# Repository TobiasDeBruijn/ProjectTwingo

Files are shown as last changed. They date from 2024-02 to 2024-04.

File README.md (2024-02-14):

# Project Twingo
I own a Renault Twingo Initiale from 2002. This car originally shipped with a simple FM radio, that wasn't enough.

## Goals
With this project I'm trying to do the following:
- Add Android Auto to the Twingo, both wireless and via USB
    - Retain the steering wheel controls
- Interior lighting
    - Replace ceiling light with LED
    - Feet of front passengers
- Replace the standard display in the middle of the dashboard? (Mine is sortof broken)
- Control AC electronically with a thermostat?

## License
All work in this project is licensed under the MIT license.

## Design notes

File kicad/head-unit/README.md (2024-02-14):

# Head unit
The 'head unit' and all the required additional stuff

## head-unit
This is the main bit of the unit. This contains the STM32 microcontroller, the Raspberry Pi running Android Auto, the DAC and various controlling relays.

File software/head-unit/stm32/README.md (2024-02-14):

# stm32-cmake-template

## Requirments
- `gcc-arm-linux-gnueabihf`
- `openocd`
- `cmake`
- `make`

## Building 
From `$ROOT/software/head-unit/stm32/`:
1. `cmake -B build -DCMAKE_BUILD_TYPE=Debug`
>Building in `Release` mode somehow causes issues
2. `cd build/`
3. `make`

## Uploading
From the repository root:
1. `openocd -f openocd-stlink.cfg -c "program build/head-unit.elf verify reset exit"`

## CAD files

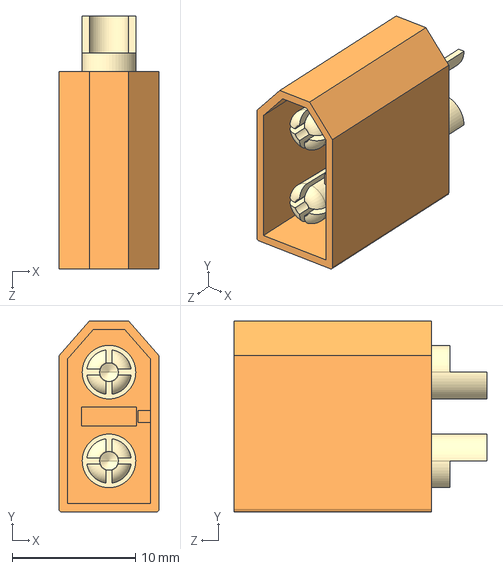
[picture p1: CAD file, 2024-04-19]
kicad/head-unit/external_symbols/xt60/XT60-M.step
8.10 x 15.5 x 20.5 mm

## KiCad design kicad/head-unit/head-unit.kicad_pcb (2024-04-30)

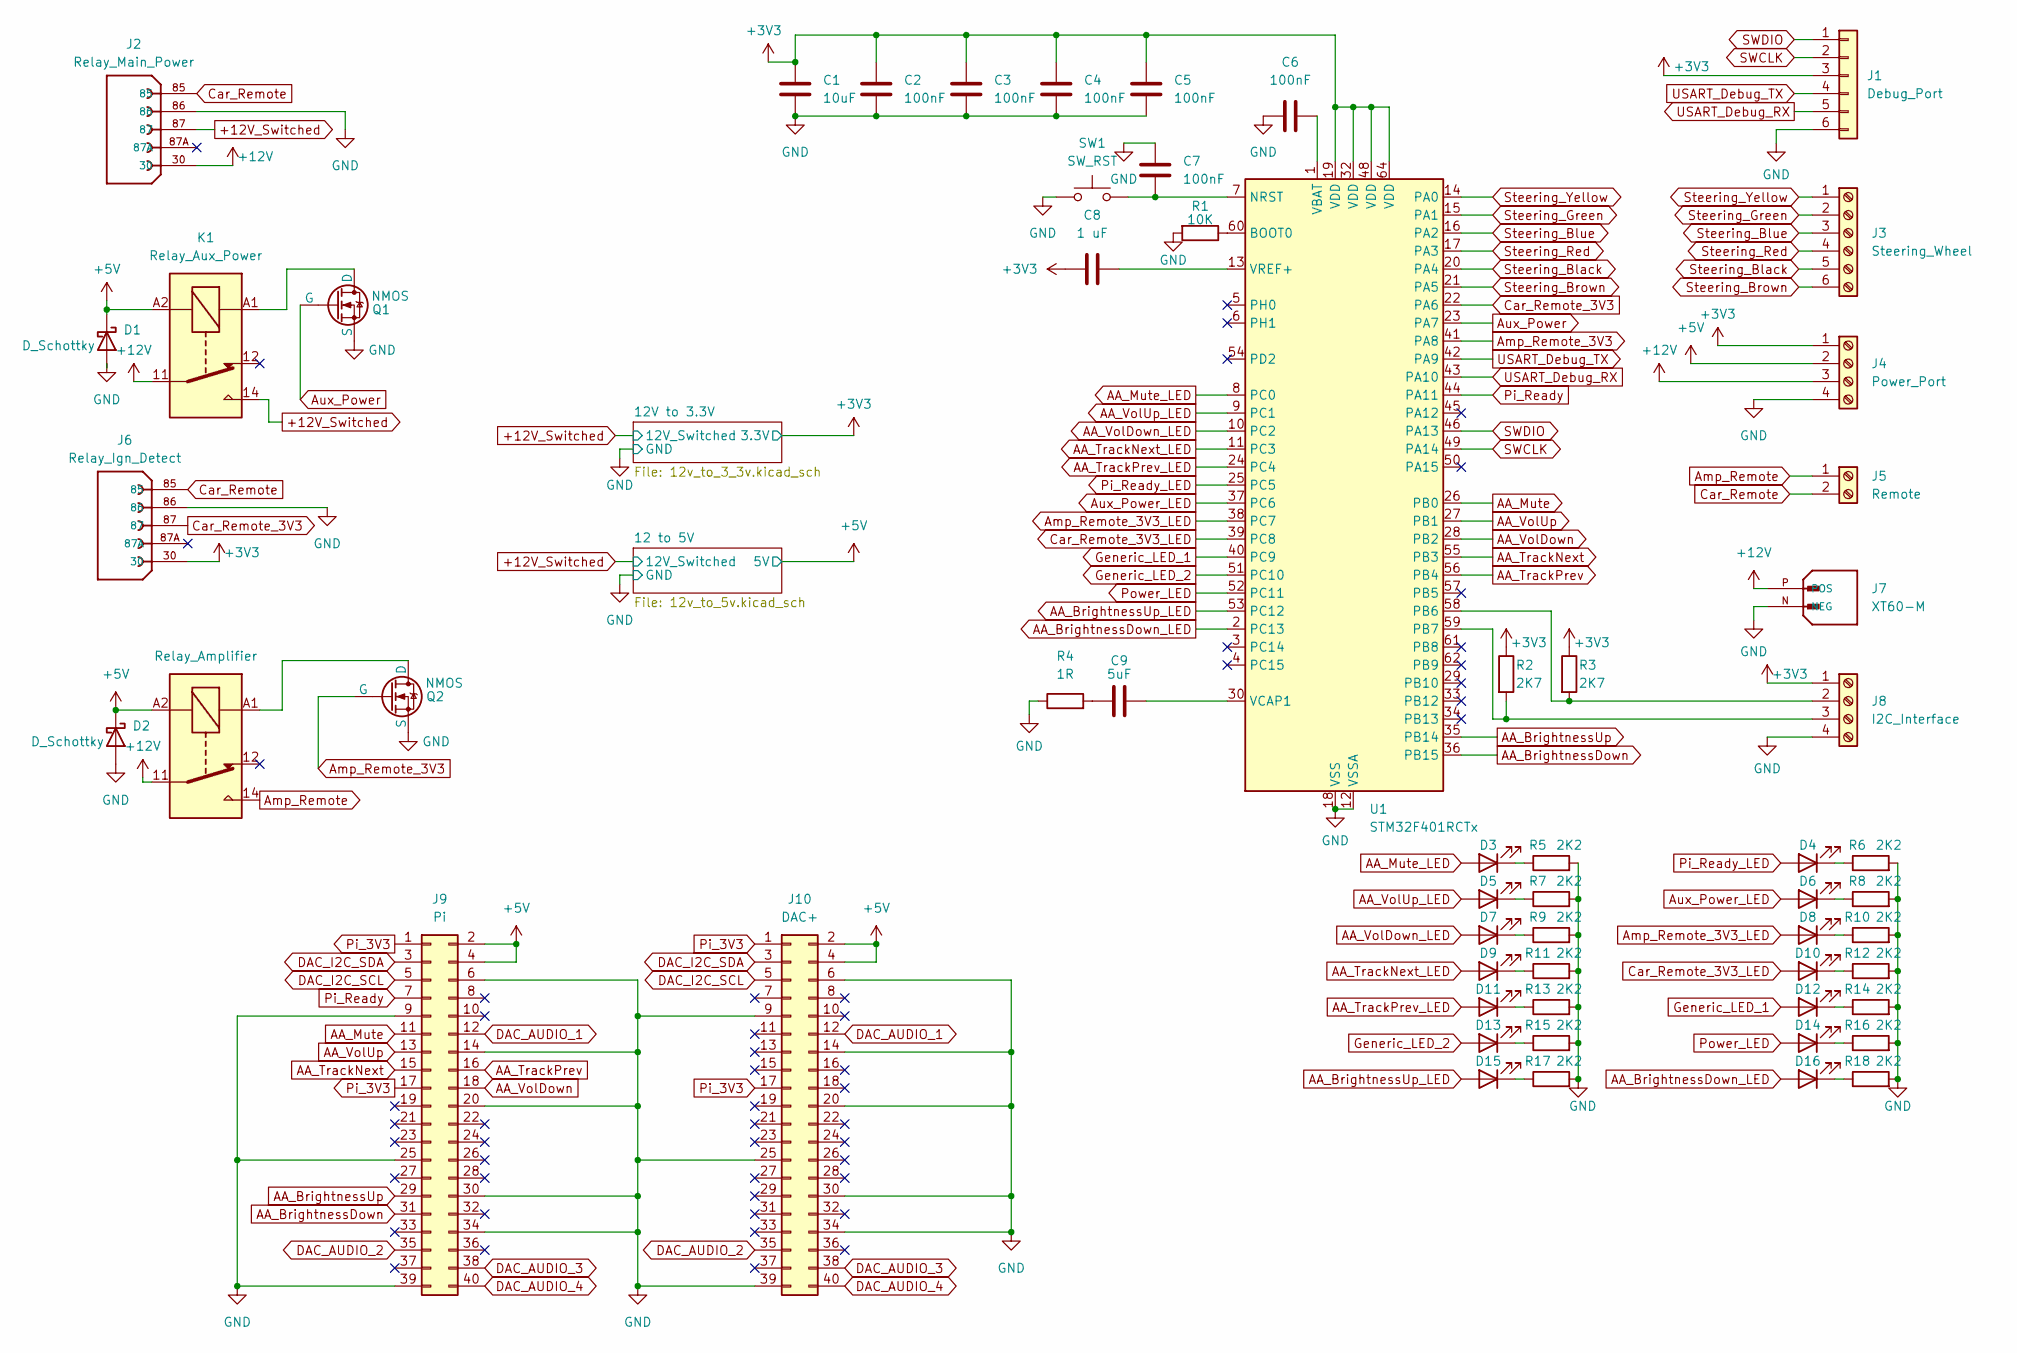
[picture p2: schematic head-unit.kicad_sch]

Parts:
C1: 10uF; C_0603_1608Metric
C2, C3, C4, C5, C6, C7: 100nF; C_0402_1005Metric
C8: 1 uF; C_0402_1005Metric
C9: 5uF; C_0603_1608Metric
D1, D2: D_Schottky; D_0603_1608Metric
D3, D4, D5, D6, D7, D8, D9, D10, D11, D12, D13, D14, D15, D16: LED; LED_0603_1608Metric
J1: Debug_Port; PinHeader_1x06_P2.54mm_Vertical
J2: Relay_Main_Power; TE_VCF4-1000; PARTREV B
J3: Steering_Wheel; TerminalBlock_bornier-6_P5.08mm
J4: Power_Port; TerminalBlock_bornier-4_P5.08mm
J5: Remote; TerminalBlock_bornier-2_P5.08mm
J6: Relay_Ign_Detect; TE_VCF4-1000; PARTREV B
J7: XT60-M; AMASS_XT60-M; PARTREV V1.2
J8: I2C_Interface; TerminalBlock_bornier-4_P5.08mm
J9: Pi; PinHeader_2x20_P2.54mm_Vertical
J10: DAC+; PinHeader_2x20_P2.54mm_Vertical
K1: Relay_Aux_Power; Relay_SPDT_Finder_36.11
K2: Relay_Amplifier; Relay_SPDT_Finder_36.11
Q1, Q2: NMOS; SW_SPDT_CK-JS102011SAQN
R1: 10K; R_0603_1608Metric
R2, R3: 2K7; R_0402_1005Metric
R4: 1R; R_0402_1005Metric
R5, R6, R7, R8, R9, R10, R11, R12, R13, R14, R15, R16, R17, R18: 2K2; R_0402_1005Metric
SW1: SW_RST; SW_Push_1P1T_NO_CK_KSC7xxJ
U1: STM32F401RCTx; LQFP-64_10x10mm_P0.5mm

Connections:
+3V3: C1.1, C2.1, C3.1, C4.1, C5.1, C8.2, J1.3, J4.1, J6.30, J8.1, R2.1, R3.1, U1.19 (VDD), U1.32 (VDD), U1.48 (VDD), U1.64 (VDD); also elsewhere on the board
+5V: D1.1 (K), D2.1 (K), J4.2, J9.2, J9.4, J10.2, J10.4, K1.A2, K2.A2; also elsewhere on the board
+12V: J2.30, J4.3, J7.P (POS), K1.11, K2.11
+12V_Switched: J2.87, K1.14; also elsewhere on the board
AA_BrightnessDown: J9.31, U1.36 (PB15)
AA_BrightnessDown_LED: D16.2 (A), U1.2 (PC13)
AA_BrightnessUp: J9.29, U1.35 (PB14)
AA_BrightnessUp_LED: D15.2 (A), U1.53 (PC12)
AA_Mute: J9.11, U1.26 (PB0)
AA_Mute_LED: D3.2 (A), U1.8 (PC0)
AA_TrackNext: J9.15, U1.55 (PB3)
AA_TrackNext_LED: D9.2 (A), U1.11 (PC3)
AA_TrackPrev: J9.16, U1.56 (PB4)
AA_TrackPrev_LED: D11.2 (A), U1.24 (PC4)
AA_VolDown: J9.18, U1.28 (PB2)
AA_VolDown_LED: D7.2 (A), U1.10 (PC2)
AA_VolUp: J9.13, U1.27 (PB1)
AA_VolUp_LED: D5.2 (A), U1.9 (PC1)
Amp_Remote: J5.1, K2.14
Amp_Remote_3V3: Q2.2 (G), U1.41 (PA8)
Amp_Remote_3V3_LED: D8.2 (A), U1.38 (PC7)
Aux_Power: Q1.2 (G), U1.23 (PA7)
Aux_Power_LED: D6.2 (A), U1.37 (PC6)
Car_Remote: J2.85, J5.2, J6.85
Car_Remote_3V3: J6.87, U1.22 (PA6)
Car_Remote_3V3_LED: D10.2 (A), U1.39 (PC8)
DAC_AUDIO_1: J9.12, J10.12
DAC_AUDIO_2: J9.35, J10.35
DAC_AUDIO_3: J9.38, J10.38
DAC_AUDIO_4: J9.40, J10.40
DAC_I2C_SCL: J9.5, J10.5
DAC_I2C_SDA: J9.3, J10.3
GND: C1.2, C2.2, C3.2, C4.2, C5.2, C6.1, C7.1, D1.2 (A), D2.2 (A), J1.6, J2.86, J4.4, J6.86, J7.N (NEG), J8.4, J9.6, J9.9, J9.14, J9.20, J9.25, J9.30, J9.34, J9.39, J10.6, J10.9, J10.14, J10.20, J10.25, J10.30, J10.34, J10.39, Q1.3 (S), Q2.3 (S), R1.2, R4.1, R5.2, R6.2, R7.2, R8.2, R9.2, R10.2, R11.2, R12.2, R13.2, R14.2, R15.2, R16.2, R17.2, R18.2, SW1.1, U1.12 (VSSA), U1.18 (VSS), U1.31 (VSS), U1.47 (VSS), U1.63 (VSS); also elsewhere on the board
Generic_LED_1: D12.2 (A), U1.40 (PC9)
Generic_LED_2: D13.2 (A), U1.51 (PC10)
unnamed: C9.2, R4.2
unnamed: D3.1 (K), R5.1
unnamed: D4.1 (K), R6.1
unnamed: D5.1 (K), R7.1
unnamed: D6.1 (K), R8.1
unnamed: D7.1 (K), R9.1
unnamed: D8.1 (K), R10.1
unnamed: D9.1 (K), R11.1
unnamed: D10.1 (K), R12.1
unnamed: D11.1 (K), R13.1
unnamed: D12.1 (K), R14.1
unnamed: D13.1 (K), R15.1
unnamed: D14.1 (K), R16.1
unnamed: D15.1 (K), R17.1
unnamed: D16.1 (K), R18.1
unnamed: J8.2, R3.2, U1.58 (PB6)
unnamed: J8.3, R2.2, U1.59 (PB7)
unnamed: K1.A1, Q1.1 (D)
unnamed: K2.A1, Q2.1 (D)
unnamed: R1.1, U1.60 (BOOT0)
unnamed: C7.2, SW1.2, U1.7 (NRST)
unnamed: C6.2, U1.1 (VBAT)
unnamed: C9.1, U1.30 (VCAP1)
unnamed: C8.1, U1.13 (VREF+)
Pi_3V3: J9.1, J9.17, J10.1, J10.17
Pi_Ready: J9.7, U1.44 (PA11)
Pi_Ready_LED: D4.2 (A), U1.25 (PC5)
Power_LED: D14.2 (A), U1.52 (PC11)
SWCLK: J1.2, U1.49 (PA14)
SWDIO: J1.1, U1.46 (PA13)
Steering_Black: J3.5, U1.20 (PA4)
Steering_Blue: J3.3, U1.16 (PA2)
Steering_Brown: J3.6, U1.21 (PA5)
Steering_Green: J3.2, U1.15 (PA1)
Steering_Red: J3.4, U1.17 (PA3)
Steering_Yellow: J3.1, U1.14 (PA0)
USART_Debug_RX: J1.5, U1.43 (PA10)
USART_Debug_TX: J1.4, U1.42 (PA9)

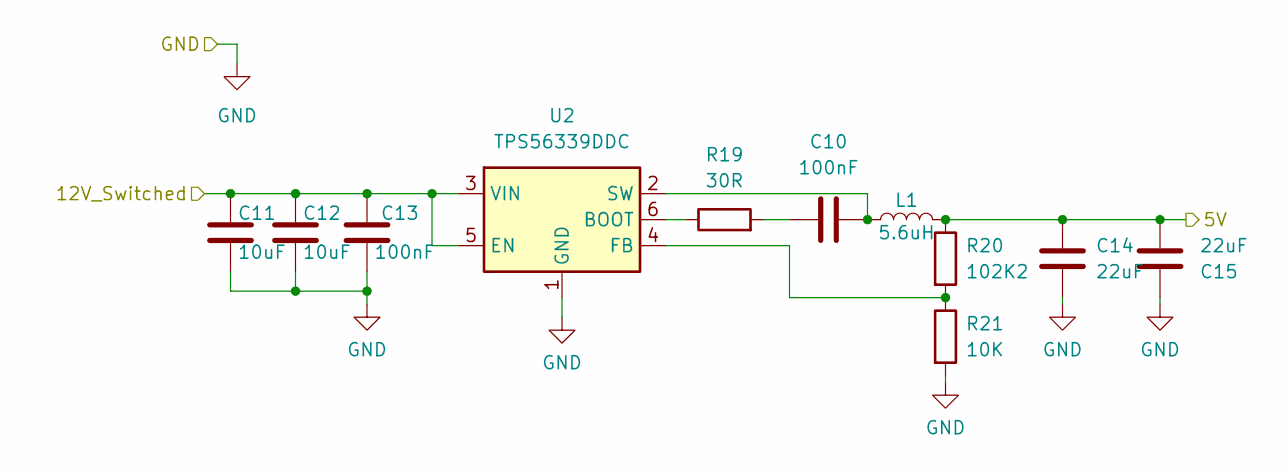
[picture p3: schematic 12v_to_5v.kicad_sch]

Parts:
C10, C13: 100nF; C_0402_1005Metric
C11, C12: 10uF; C_0603_1608Metric
C14, C15: 22uF; C_0603_1608Metric
L1: 5.6uH; L_6.3x6.3_H3
R19: 30R; R_0201_0603Metric
R20: 102K2; R_0805_2012Metric
R21: 10K; R_0603_1608Metric
U2: TPS56339DDC; SOT-23-6

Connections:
+5V: C14.1, C15.2, L1.2, R20.1; also elsewhere on the board
+12V_Switched: C11.1, C12.1, C13.1, U2.3 (VIN), U2.5 (EN); also elsewhere on the board
GND: C11.2, C12.2, C13.2, C14.2, C15.1, R21.2, U2.1 (GND); also elsewhere on the board
unnamed: C10.1, R19.2
unnamed: R19.1, U2.6 (BOOT)
unnamed: R20.2, R21.1, U2.4 (FB)
unnamed: C10.2, L1.1, U2.2 (SW)

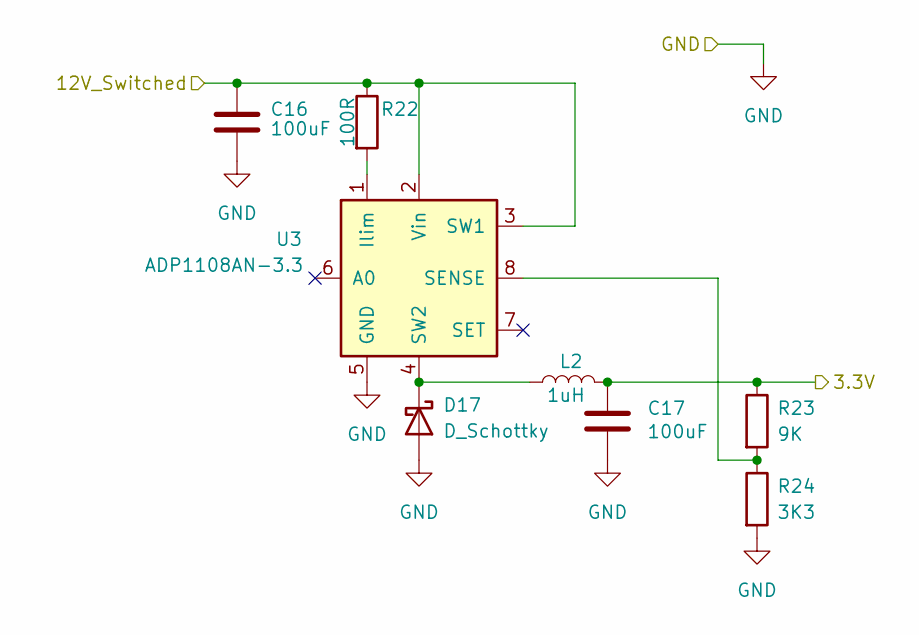
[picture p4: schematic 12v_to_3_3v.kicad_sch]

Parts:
C16, C17: 100uF; C_1206_3216Metric
D17: D_Schottky; D_0603_1608Metric
L2: 1uH; L_0402_1005Metric
R22: 100R; R_0402_1005Metric
R23: 9K; R_0603_1608Metric
R24: 3K3; R_0603_1608Metric
U3: ADP1108AN-3.3; DIP-8_W7.62mm

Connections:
+3V3: C17.1, L2.2, R23.1; also elsewhere on the board
+12V_Switched: C16.1, R22.1, U3.2 (Vin), U3.3 (SW1); also elsewhere on the board
GND: C16.2, C17.2, D17.2 (A), R24.2, U3.5 (GND); also elsewhere on the board
unnamed: D17.1 (K), L2.1, U3.4 (SW2)
unnamed: R22.2, U3.1 (Ilim)
unnamed: R23.2, R24.1, U3.8 (SENSE)

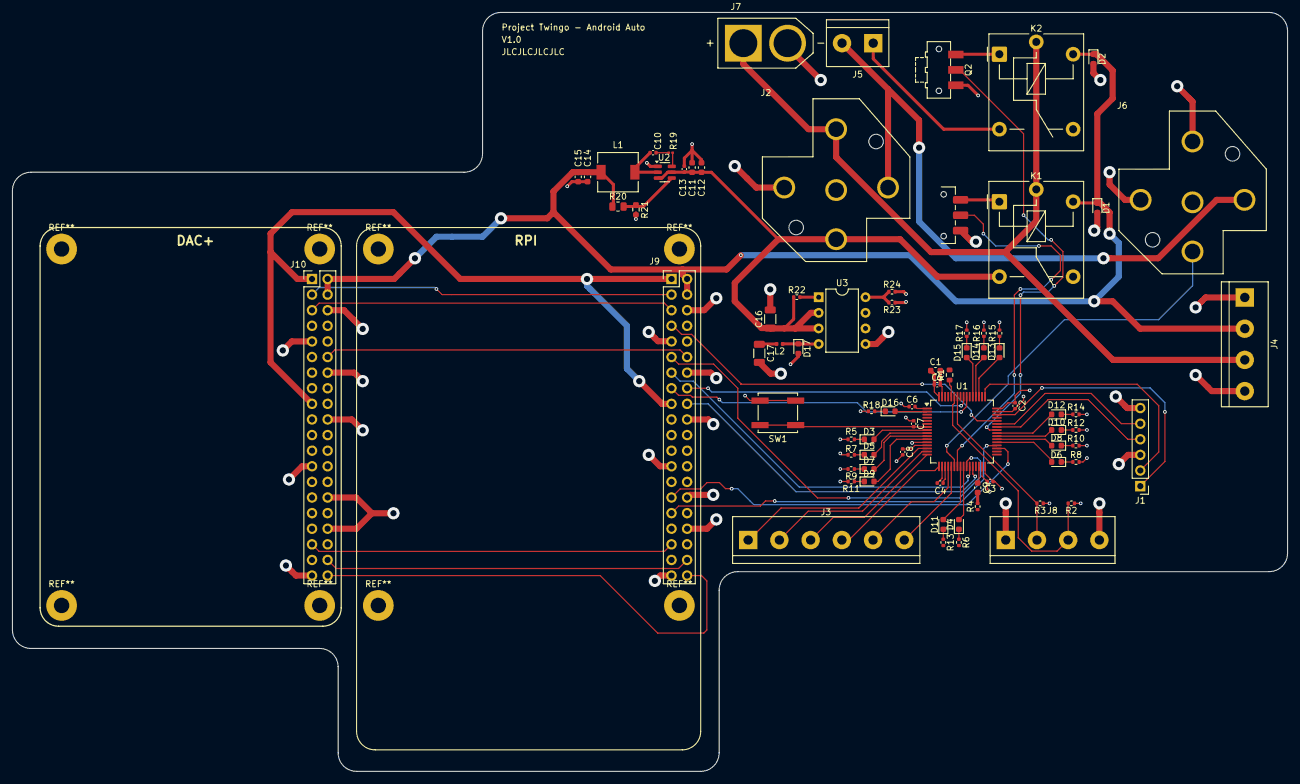
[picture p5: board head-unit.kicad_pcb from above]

Board: 4 copper layers, 207.5 x 123.5 mm, 78 parts (0 on the bottom side), 80 nets.

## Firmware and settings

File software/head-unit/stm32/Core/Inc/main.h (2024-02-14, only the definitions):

#define Debug_LED_Pin GPIO_PIN_0
#define Debug_LED_GPIO_Port GPIOA
#define Volume_Up_Pin GPIO_PIN_1
#define Volume_Up_GPIO_Port GPIOA
#define Volume_Down_Pin GPIO_PIN_2
#define Volume_Down_GPIO_Port GPIOA
#define Track_Next_Pin GPIO_PIN_3
#define Track_Next_GPIO_Port GPIOA
#define Stereo_Remote_Pin GPIO_PIN_0
#define Stereo_Remote_GPIO_Port GPIOB
#define Secondary_Power_Pin GPIO_PIN_1
#define Secondary_Power_GPIO_Port GPIOB
#define Remote_Detect_Pin GPIO_PIN_2
#define Remote_Detect_GPIO_Port GPIOB
#define Debug_UART_TX_Pin GPIO_PIN_10
#define Debug_UART_TX_GPIO_Port GPIOB
#define Debug_UART_RX_Pin GPIO_PIN_11
#define Debug_UART_RX_GPIO_Port GPIOB
#define Steering_Wheel_Red_Pin GPIO_PIN_12
#define Steering_Wheel_Red_GPIO_Port GPIOB
#define Steering_Wheel_Green_Pin GPIO_PIN_13
#define Steering_Wheel_Green_GPIO_Port GPIOB
#define Steering_Wheel_Yellow_Pin GPIO_PIN_14
#define Steering_Wheel_Yellow_GPIO_Port GPIOB
#define Steering_Wheel_Brown_Pin GPIO_PIN_15
#define Steering_Wheel_Brown_GPIO_Port GPIOB
#define Volume_Mute_Pin GPIO_PIN_11
#define Volume_Mute_GPIO_Port GPIOA
#define Programmer_DIO_Pin GPIO_PIN_13
#define Programmer_DIO_GPIO_Port GPIOA
#define Programmer_CLK_Pin GPIO_PIN_14
#define Programmer_CLK_GPIO_Port GPIOA
#define Steering_Wheel_Black_Pin GPIO_PIN_8
#define Steering_Wheel_Black_GPIO_Port GPIOB
#define Steering_Wheel_Blue_Pin GPIO_PIN_9
#define Steering_Wheel_Blue_GPIO_Port GPIOB

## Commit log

2024-02-14 Initial commit: - WIP Head unit Kicad files - WIP Head unit STM firmware
    [head-unit.kicad_sch]
2024-02-14 Relays, cleanup
    [head-unit.kicad_sch]
2024-04-18 Work on head unit
    [head-unit.kicad_pcb, head-unit.kicad_sch]
2024-04-18 Initial work on headunit
    [head-unit.kicad_pcb]
2024-04-18 Kicad changes
    [head-unit.kicad_sch]
2024-04-19 Dankje Douwe
    [12v_to_5v.kicad_sch, head-unit.kicad_sch, untitled.kicad_sch]
2024-04-19 Fix mosfets, switch to screw terminals and XT60
    [12v_to_3_3v.kicad_sch, 12v_to_5v.kicad_sch, XT60-M.step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]
2024-04-20 Add I2C, begin routing
    [12v_to_3_3v.kicad_sch, 12v_to_5v.kicad_sch, head-unit.kicad_pcb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]
2024-04-24 WIP routing
    [12v_to_3_3v.kicad_sch, 12v_to_5v.kicad_sch, head-unit.kicad_pcb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]
2024-04-24 More routing
    [head-unit.kicad_pcb]
2024-04-29 Fix pi moutning holes?
    [head-unit.kicad_pcb]
2024-04-29 Routing to pi
    [head-unit.kicad_pcb]
2024-04-30 Outline for DAC+; board outline
    [head-unit.kicad_pcb]

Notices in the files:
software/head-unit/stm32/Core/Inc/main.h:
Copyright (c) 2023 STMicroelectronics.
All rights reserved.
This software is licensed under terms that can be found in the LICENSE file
